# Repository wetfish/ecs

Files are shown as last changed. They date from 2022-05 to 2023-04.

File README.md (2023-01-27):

# ecs
Environmental control systems

---

# sensorlogger.py
Used for logging temperature data to a raspberry pi's SD card. Requires DS18B20, DHT11, or DHT22 sensor.
### Super basic instructions

- Write raspberry pi OS to an SD card
- Run `sudo apt update`
- Then `sudo apt install python3-pip`
- Then `pip3 install -r requirements.txt`
- Then `python3 simplelogger.py 26 dht11`

#### Installation and usage
Requires python 3

Requires 1-wire interface to be enabled in raspi-config for ds18b20 sensor https://www.raspberrypi-spy.co.uk/2018/02/enable-1-wire-interface-raspberry-pi/

To install dependencies:

`pip install -r requirements.txt`
  
Usage:

`python3 sensorlogger.py [GPIO pin #] [Sensor type] {-f output filename}`

GPIO pin # and sensor type required. When -f is used, an output filename can be specified for the log file, defaults to [sensorname].log when -f is not used

GPIO pin # is the BCM pin #, not the board pin # https://raspberrypi.stackexchange.com/questions/12966/what-is-the-difference-between-board-and-bcm-for-gpio-pin-numbering

Sensor type is all lower case. dht11, dht22, or ds18b20

## quickcsvplotter.py
Plots the data collected by sensorlogger.py

Usage:

`python3 quickcsvplotter.py [csv filename 1] [csv filename 2] ... [csv filename n]`

Providing filenames in command line is optional. If no filenames are specified, all csvs in current directory will be plotted.

---

# sensorlogger.ino
Used to log data from a variety of sensors to an SD card, using a  NodeMCU ESP8266 devkit. Other devices can be used, but some cannot fit the full program onto the flash memory. Also prints data to serial (115200 BAUD) , so can be monitored while running as well. A continuously flashing LED indicates an error with either the SD card or one of the sensors.

### Supported sensors:
- DS18B20
- BME280
- Phototransistor (like PT334-6C)
- INA219
- Anemometer

### Log file:
The first line acts as column headers for the rest of the file. Each of the following lines consist of comma separated values for each of the measurements being taken. Each line is a seperate set of measurements.

### Error blink code:
- 2x blink: SD initialization error
- ~10x blink: SD init ok, but SD write error

## Flashing the NodeMCU ESP8266
To add support for NodeMCU board to Arduino IDE:

1. Go to File -> Preferences -> "Additional Boards Manager URLs:", and paste https://arduino.esp8266.com/stable/package_esp8266com_index.json into the box. Click OK.
2. Now click Tools -> Board: -> "Boards Manager...". In the seach bar, type "esp8266". Click on the esp8266 package, then click "Install".
3. Restart Arduino IDE. Click Tools -> Board: -> ESP8266 Boards -> NodeMCU 1.0 (ESP-12E Module)

To install required libraries:

- Click Tools -> Manage Libraries..., then enter [library name] into search bar. Click "Install". If you are asked if you also want to install missing dependencies, click "Install All".

Do the above step for the following libraries:
 - Dallas Temperature
 - Adafruit BME280 Library
 - Adafruit ADS1X15
 - Adafruit INA219

 Now you should be able to open the sensorlogger.ino sketch in the Arduino IDE and upload it to the NodeMCU ESP board.

 ## sensorlogger.ino parameters
 Near the top of sensorlogger.ino, there is a list of parameters than can be changed according to your own hardware setup.

 **LOG_FILENAME** -> This is a string indicating the name of the log file. It must fit the 8.3 short format, so it can have a maximum of 8 characters, a period, and then 3 more characters. Each time the program is restarted, a new file is created, so if your LOG_FILENAME = "log.txt", log.txt will be created on the SD card. On subsequent runs, an underscore and a numeral will be appended to the filename.

 **POLL_INTERVAL** -> This is how long to wait between sensor readings, in milliseconds. 

 **NO_SD** -> This is a boolean that allows the program to run without an SD card connected. Set to "true" to run program without SD card, "false" if you want to write data to SD.

 **SENSORS** -> This is an array that represents which sensors to take readings from. Each element is a struct of {(enum)[sensor type], (uint8_t)[pin number or hardware address]}. Valid sensor types are: ds18b20, voltmeter, bme280, ads1115, ads1115anemometer, and ina219. For the INA219, the second field will need to contain the hardware address. If you have not altered the INA219 module at all, the address is 0x40. For the BME280, the second field is irrelevant and any int works. For the devices connected through the ADS1115, the second field is the pin on that board.

 **DS18B20ADDRESSES** -> This is an array of the addresses of DS18B20 sensors being used and a corresponding label for each one. The addresses are device-specific, so will need to found by running ds18b20AddressFinder.ino with each of your sensors. The label will appear at the column header in the log file so we know which temperature readings come from which sensors.

**CS_PIN** -> This is the chip select (CS) pin for the SPI interface af the SD card. 

**LED_PIN** -> This is the pin for the indicator LED. By default it is one of the built-in LEDs on the NodeMCU, but can be an external one if desired.

# ds18b20AddressFinder.ino
Use this to find addresses of all DS18B20 sensors being used. Make sure to mark each sensor as well so they don't get mixed up. It only requires the DallasTemperature library, which should have already been installed.

## ds18b20AddressFinder.ino parameters

**ONEWIRE_PIN** -> This is the pin that the data wire of the DS18B20 is connected to.

## Getting your device addresses
1. Connect first sensor to NodeMCU with ds18b20AddressFinder.ino.
2. Connect NodeMCU to computer with Arduino IDE (or other serial monitor).
3. Open serial monitor and make sure it's at 115200 BAUD.
4. Every 5 seconds, the sensor's address will be printed. Copy that to sensorlogger.ino or just record it for later.
5. Repeat for each DS18B20 you intend to use. Remember to indicate somehow which sensor corresponds to which address.

---

# sensorserial.ino and get_data_from_mcu.py
Used to send data from a variety of sensors to a PC via USB, using a  NodeMCU ESP8266 devkit. A continuously flashing LED indicates an error with either the SD card or one of the sensors. This program is very similar to sensorlogger.ino, but it sends data to a PC running a python script rather than log to SD, and the python script controls the timiing of the sensor polls.

## Setting up NodeMCU ESP8266
Follow the same steps as for sensorlogger.ino. Then plug the NodeMCU via USB into a computer that will run the python script.

## get_data_from_mcu.py
To be run from terminal on a PC, Raspberry Pi, etc:

`python3 get_data_from_mcu.py [poll_interval]`

[poll_interval] is the time in seconds between sensor polls, and is an optional argument. Default poll interval is 3 seconds.

Whenever restarting script, NodeMCU should be restarted as well.

# GoPro as webcam setup
https://github.com/jschmid1/gopro_as_webcam_on_linux

- Install gopro_as_webcam_on_linux:

	`sudo su -c "bash <(wget -qO- https://cutt.ly/PjNkrzq)" root`

- Install dependencies:

	`sudo apt install ffmpeg v4l2loopback-dkms curl vlc`

- Plug gopro into computer via USB (can be without battery and sd card) and in new terminal:

	`sudo gopro webcam -n -a`

	This starts gopro in webcam mode using auto settings (-a), and no input from user (-n).

- Check for the device id with:

	`ls -l dev/video*`

	This is my result:

	>crw-rw----+ 1 root video 81, 0 Jan  9  2022 /dev/video0
	>
	>crw-rw----+ 1 root video 81, 1 Jan  9  2022 /dev/video1
	>
	>crw-rw----+ 1 root video 81, 2 Jan 25 14:40 /dev/video42

	/dev/video0 and 1 both referred to the laptop's webcam, so /dev/video42 is the gopro.

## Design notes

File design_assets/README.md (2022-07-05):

shelter assembly

## 3D Printed Parts
All 3D printed parts should be printed in PETG or other plastic that can withstand some heating.

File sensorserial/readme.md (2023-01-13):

## Sensorserial for NodeMCU dev board (ESP8266) and a computer running python scripts

If using Arduino IDE to program microcontroller, rename src/main.cpp to sensorserial.ino

Connect microcontroller that is running sensorserial program to a computer via USB. On the computer, run get_data_from_mcu.py to generate a log file from the microcontroller's sensor readings.

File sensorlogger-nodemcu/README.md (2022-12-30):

## Sensorlogger for NodeMCU dev board (ESP8266)

If using Arduino IDE to program microcontroller, rename src/main.cpp to sensorlogger.ino

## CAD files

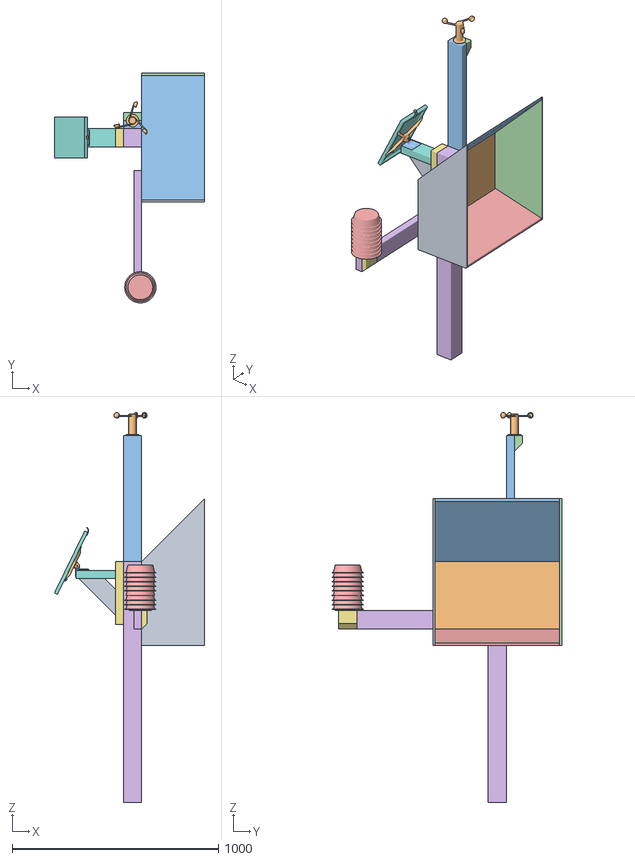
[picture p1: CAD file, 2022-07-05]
design_assets/mount_and_shelter_design v6.obj
727.6 x 1114.1 x 1890.0
left panel
back panel
top panel
right_panel
bottom panel
2x4-vert
2x4-horiz
2x4-brace

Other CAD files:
design_assets/Enclosure drain v15.f3d
design_assets/INA219_mount v14.f3d
design_assets/LM2596_mount_double v5.f3d
design_assets/MCU_PCB_mount v14.f3d
design_assets/ads1115_mount v10.f3d
design_assets/battery shim v4.f3d
design_assets/battery_clip v1.f3d
design_assets/cable gland inserts v3.f3d
design_assets/header_bus_mount v4.f3d
design_assets/mount_and_shelter_design v5.f3z
design_assets/panel_mount v25.f3d
design_assets/stevenson_spacer_2nd_bottom v2.f3d
design_assets/stevenson_spacer_and_template v20.f3d
design_assets/stevenson_spacer_bottom v5.f3d
design_assets/stevenson_spacer_top v2.f3d
design_assets/wanderer_mount v2.f3d

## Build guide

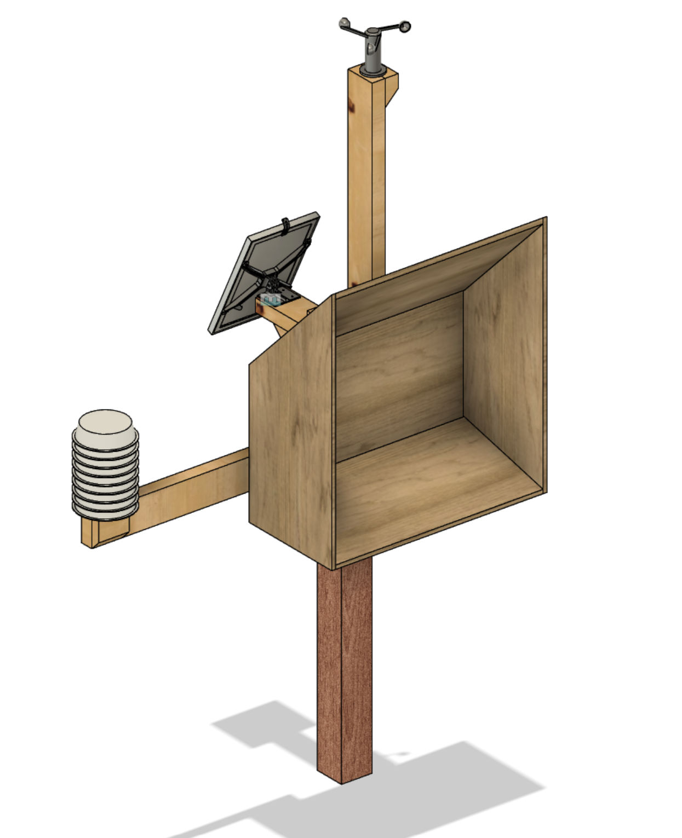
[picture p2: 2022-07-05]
design_assets/shelter assembly.png

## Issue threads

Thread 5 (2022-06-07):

Add phototransistor-specific reading to sensorlogger.ino

quinnc0, 2022-06-07:
The program currently sees this sensor as just a voltmeter, but the raw voltage reading isn't very intuitive. A threshold voltage to determine whether there is or isn't light might be more useful. Some outdoors testing may be required to determine what readings occur under what lighting conditions.

Closed 2022-06-23.

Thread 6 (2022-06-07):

Test anemometer to determine characteristics of output signal

quinnc0, 2022-06-07:
The anemometer's signal is expected to be under 2V. If this is true, the ADS gain might be able to be set for higher precision. Also, it may be useful to test that the voltage to windspeed mapping in sensorlogger.ino is correct, though I'm not sure of a good way to calibrate that.

quinnc0, 2022-09-19:
The current voltage to windspeed mapping definitely seems off. It seems to report windspeeds much lower than expected, but I don't know by how much. Current mapping is based on the data from[ adafruit's product page](https://www.adafruit.com/product/1733). It should be confirmed that this mapping is implemented correctly, and if so, devise a way to calibrate the sensor better.

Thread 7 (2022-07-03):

NodeMCU usually fails to boot with SD card inserted.

quinnc0, 2022-07-03:
This is a very intermittent problem so it has been hard to diagnose the cause of it. When an SD card is inserted into the SD card reader, the NodeMCU can fail to boot. As a workaround, a 3s delay was added to the beginning of the sensorlogger.ino program to allow the SD card to be inserted just after boot. This workaround doesn't always work either, but it's more consistent.

quinnc0, 2022-09-22:
SD card was replaced on 9/18. So far it has booted fine with the new SD card, but due to the intermittent nature of the problem, it's probably too early to determine if  the issue is truly fixed.

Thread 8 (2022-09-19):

BME sensor failure

quinnc0, 2022-09-19:
The BME sensor failed sometime within 2 months after installation. This may be due to moisture, as the wind was a lot stronger than I anticipated. If so, this could be a simple fix of either shielding the sensor better from rain, or simply swapping a waterproof ds18b20 into the BME's position.

quinnc0, 2023-01-25:
Cause of sensor failure still undetermined, but BME was replaced and better shielded from rain and debris. So far so good.

Closed 2023-01-25.

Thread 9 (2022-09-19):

Sensor failure causes microcontroller reboot

quinnc0, 2022-09-19:
Program should be rewritten to allow sensor failure without rebooting microcontroller. This should be how it works with some of the sensors already, but at least the BME280 will not allow the program to run when missing. The BME280 uses I2C communication, so possibly the other I2C devices will fail in a similar manner (INA219 & ADS1115).

It would be much better to just gather garbage data on failed sensors because at least we'd still get the data from the working sensors.

quinnc0, 2022-09-22:
All I2C sensors will return NAN when they had failed or were not present. Previously, the program kept trying to get a reading until it no longer returned NAN. The nodeMCU times out and reboots after spending a few seconds without repeating its main loop. So it would reboot when a sensor returned NAN for a few seconds. Now the sensors will only retry a few times before accepting a NAN result.

Closed 2022-09-22.

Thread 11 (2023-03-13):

Station M1 too weak to handle Gopro webcam stream?

quinnc0, 2023-03-13:
For some reason, gopro will not stream at any other resolution than 1080, and at 30 fps. Station M1 can only process about 7 fps at that resolution it seems. This leads to clips being delayed by minutes. Also, after some time, the webcam stream buffer is filled and then I think it just starts dropping frames.

The Station M1 was tested with cheap logitech webcam that outputs 320x240 at 30 fps. There is no problem handling this stream and clips are generated in real time and at the correct speed.

Maybe there is a way to lower the gopro resolution to allow the Station M1 to keep up. Otherwise I think the only options are finding a more suitable camera or a more powerful sbc.

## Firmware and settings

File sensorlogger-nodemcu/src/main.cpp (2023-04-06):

#include <SPI.h>
#include <SD.h> // http://www.arduino.cc/en/Reference/SD

/* 
https://www.milesburton.com/Dallas_Temperature_Control_Library (for DS18B20)
https://github.com/adafruit/Adafruit_BME280_Library 
https://github.com/adafruit/Adafruit_ADS1X15 (ADC board)
https://github.com/adafruit/Adafruit_INA219 (Volt/Ammeter)
*/

#include "sensorwrap.h"
#include "ds18b20wrap.h"
#include "voltmeterwrap.h"
#include "bme280wrap.h"
#include "ads1115voltmeterwrap.h"
#include "ads1115anemometerwrap.h"
#include "ads1115phototransistorwrap.h"
#include "ina219wrap.h"

#include "oleddisplay.h"

// These are the valid sensor models than can be used.
enum SensorModels
{/*dht11, dht22,*/ ds18b20, voltmeter, bme280, ads1115, ads1115anemometer, ads1115phototransistor, ina219};
struct SensorInfo
{
	SensorModels model;
	uint8_t pin; // data pin of that sensor - for I2C devices, this usually is arbitrary
};

// Pins printed on the NodeMCU board are not the same as the esp8266 GPIO pin number, which is what we actually need to use here
namespace NodeMcuPins
{
	enum : uint8_t
	{
		D0 = 16, D1 = 5, D2 = 4, D4 = 2,
		D5 = 14, D6 = 12, D7 = 13, D8 = 15,
		RX = 3, TX = 1, SD2 = 9, SD3 = 10
	};
}
namespace Ads1115Pins
{
	enum : uint8_t
	{
		A0 = 0, A1 = 1, A2 = 2, A3 = 3
	};
}
//----------------------------------------------------------
// Change filename, polling interval, SD logging, and sensor types here
const String LOG_FILENAME = "log.txt"; // first line is column labels, so throw that away when using the file for computations
const unsigned long POLL_INTERVAL = 3000; // in milliseconds
const bool NO_SD = false; // disables sd card logging
const SensorInfo SENSORS[] = 
{// {sensor model, pin # (or I2C address for INA219)}
	{ina219, 0x40}, 
	{ina219, 0x41}, 
	//{ads1115, Ads1115Pins::A0}, 
	{bme280, 0},
	{ds18b20, NodeMcuPins::SD3},
	{ads1115phototransistor, Ads1115Pins::A0},
	{ads1115anemometer, Ads1115Pins::A1},
	//{voltmeter, A0}
};

// --- DS18B20 Addresses ---
// List sensor addresses here. Get them individually with ds18b20AddressFinder.ino or similar
// Labels should be where the sensor is located or something. Or some identifying factor.
const DS18B20Addresses DS18B20_ADDRESSES[] = {
		//{{0x28, 0x63, 0x1B, 0x49, 0xF6, 0xAE, 0x3C, 0x88}, "MAIN"}, // measuring electronics enclosure temp,has white heatshrink
		{{0x28, 0xDC, 0xA0, 0x49, 0xF6, 0xEB, 0x3C, 0xF0}, "Batt"}, // measuring battery enclosure temp, has white heatshrink
		{{0x28, 0x6A, 0x64, 0x49, 0xF6, 0xBE, 0x3C, 0xF0}, "MCU"} // has red heatshrink
		};

uint8_t NUM_SENSORS = sizeof(SENSORS) / sizeof(SENSORS[0]);
uint8_t NUM_DS18B20S = sizeof(DS18B20_ADDRESSES) / sizeof(DS18B20_ADDRESSES[0]);

//----------------------------------------------------------
// Other Pin selection
// Pins D5 (SCK), D6(MISO), D7(MOSI), and D8(CS) on NodeMCU are required for the SPI for the SD card reader, so don't use them.
// On NodeMCU, pin D1(SCL) and D2(SDA) for I2C communication
const uint8_t CS_PIN = NodeMcuPins::D8;// cs pin for sd card
const uint8_t LED_PIN = LED_BUILTIN_AUX; // led pin for indicator. not required.

/*
// DHT sensors
class DhtWrap : public SensorWrap
{
	private:
	DHT dht;

	public:
	DhtWrap(uint8_t pin_num, uint8_t dht_type): dht(pin_num, dht_type)
	{
		num_readings = 2; // 1 temp and 1 humidity
		labels = "DHT-Temp(F), DHT-RH(%)";
	}

	void init()
	{
		Serial.println("DHT init");
		dht.begin();
	}

	float takeReading(uint8_t reading_num)
	{
		switch (reading_num)
		{
			case 0:
				return dht.readTemperature(true); // true for F, false for C
			case 1:
				return dht.readHumidity();
			default:
				return NAN;
		}
	}
};
*/

/* --------------
 * Linked list for storing list of sensors.
 * TODO: maybe get rid of list_size. Doesn't look like it's being used. or maybe just use it.
 */
template <typename T>
class LinkedList
{
	
	public:

	struct Node
	{
		T sensor;
		Node* next;
	};

	Node* head;
	uint8_t list_size;

	LinkedList<T>()
	{
		head = nullptr;
		list_size = 0;
	}

	
	Node* get_next_node(Node* curr_node)
	{
		return curr_node->next;
	}

	// add node to end of list and return pointer to that node, in case it's needed
	Node* push_back(T newData)
	{
		Node* new_node = get_new_node(newData);
		if (head == nullptr) // if this ia the start of the list
		{
			head = new_node;
		}
		else                // if this is adding to an existing list
		{
			Node* curr_node = head;
			while (curr_node->next)
			{
				curr_node = curr_node->next;
			}
			curr_node->next = new_node;
			list_size++;
		}
		return new_node;
	}

	private:
	// creates new node
	Node* get_new_node(T newSensor)
	{
		Node* newNode = new Node;
		newNode->sensor = newSensor;
		newNode->next = nullptr;
		return newNode;
	}
};

/* =================================
 * DataLogger
 * Makes list of sensors, writes data from each of them to a new file based on the given filename base.
 * Uses LinkedList class and all of the SensorWrap children.
 * //TODO: possibly restructure this so it's easier to actually access and do stuff with any 
 *  of the sensor values.
 */
class DataLogger
{
	String log_fn;
	String column_labels;
	uint8_t cs_pin;
	uint8_t led_pin;
	unsigned long poll_interval;
	unsigned long last_poll;
	LinkedList<SensorWrap*>* sensor_list = new LinkedList<SensorWrap*>();
	bool did_err_msg = false;

	uint8_t total_num_readings; // total number of readings per update
	float last_sensor_readings[25]; // this should be large enough for all of our readings.

	OledDisplay display;
	
	public:
	/* 
	 * logFn- filename should be short so as to conform to 8.3 short format (8 characters + '.' + 3 characters)
	 * pollInterval- time between sensor polls in milliseconds	 *
	 */
	DataLogger(String logFn, uint8_t CSpinNo, uint8_t LEDpinNo, unsigned long pollInterval) : 
	log_fn(logFn) 
	{
		cs_pin = CSpinNo;
		led_pin = LEDpinNo;
		poll_interval = pollInterval;
		last_poll = 0;
		column_labels = "Time(s)";
		total_num_readings = 1; // we will always at least be recording time
	}
	
	// initializers. these are run in setup()
	void init_sd()
	{
		if(NO_SD)
		{
			Serial.println("Not logging to SD.");
			return;
		}
		Serial.println("CS_pin: " + String(cs_pin));
		Serial.println("led_pin: " + String(led_pin));
		Serial.println("Poll Intvl: " + String(poll_interval));

		// set up led
		pinMode(led_pin, OUTPUT);
		Led(true);

		// check if sd card is not set up
		while (!SD.begin(cs_pin))
		{
			// error
			Serial.println("SD err " + String(cs_pin));
			//error_blink();
			// blink 2x quick, then try again
			Led(true);
			delay(100);
			Led(false);
			delay(100);
			Led(true);
			delay(100);
			Led(false);
			delay(700);

		}
		Led(true);
		// get the right filename
		log_fn = set_next_filename();
	}

	void init_sensors(const SensorInfo sensors[], uint8_t& num_sensors)
	{
		display.init();
		list_sensors(sensors, num_sensors);
		// iterate through list of sensors to get the column labels from all of them
		LinkedList<SensorWrap*>::Node* current_sensor = sensor_list->head;
		while(current_sensor)
		{
			current_sensor->sensor->init();
			column_labels += ", " + current_sensor->sensor->labels;
			total_num_readings += current_sensor->sensor->num_readings;
			current_sensor = sensor_list->get_next_node(current_sensor);
		}
		// show what each column means
		Serial.println("\n" + column_labels);
		if(!NO_SD)
		{	// when parsing the CSV, either throw away all lines starting with #, or just the first line
			write_file("# " + column_labels);
		}
		//Serial.println("-------------------------------");
	}

	// takes readings and writes to file
	void update()
	{
		if(timekeeper())
		{
			String sensor_data = read_from_sensors();
			Serial.println(sensor_data);
			oled_display();
			// if not using sd stop here
			if(NO_SD)
			{
				return;
			}
			write_file(sensor_data);
		}
	}

	private:
	
	// populate list
	// add another case for each new sensor class added 
	void list_sensors(const SensorInfo sensors[], uint8_t& num_sensors)
	{
		for (int i = 0; i < num_sensors; i++)
		{
			switch (sensors[i].model)
			{
			//case dht11:
			//	sensor_list->push_back(new DhtWrap(sensors[i].pin, DHT11));
			//	break;
			//case dht22:
			//	sensor_list->push_back(new DhtWrap(sensors[i].pin, DHT22));
			//	break;
			case ds18b20:
			{
				LinkedList<SensorWrap*>::Node* this_node;
				this_node = sensor_list->push_back(new DS18B20Wrap(sensors[i].pin));
				LinkedList<DS18B20Wrap*>::Node* ds_node = (LinkedList<DS18B20Wrap*>::Node*)this_node;
				ds_node->sensor->set_addresses(DS18B20_ADDRESSES, NUM_DS18B20S);
			}
				break;
			case voltmeter:
				sensor_list->push_back(new VoltmeterWrap(sensors[i].pin));
				break;
			case bme280:
				sensor_list->push_back(new BME280Wrap());
				break;
			case ads1115:
				sensor_list->push_back(new ADS1115VoltmeterWrap(sensors[i].pin));
				break;
			case ads1115anemometer:
				sensor_list->push_back(new ADS1115AnemometerWrap(sensors[i].pin));
				break;
			case ads1115phototransistor:
				sensor_list->push_back(new ADS1115PhototransistorWrap(sensors[i].pin));
				break;
			case ina219:
				sensor_list->push_back(new INA219Wrap(sensors[i].pin));
				break;
			default:
				break;
			}
		}
	}

	// increments filename if one already exists with given name.
	String set_next_filename()
	{
		String temp_fn = log_fn;
		String base_fn;
		String extension;
		unsigned long i = 1;
		if (SD.exists(temp_fn))
		{
			size_t dot_loc= temp_fn.lastIndexOf(".");
			base_fn = temp_fn.substring(0, dot_loc);
			extension = temp_fn.substring(dot_loc);

			while (SD.exists(temp_fn))
			{
				String i_string = "_" + String(i);
				if (base_fn.length() + i_string.length() > 8)
				{
					base_fn = base_fn.substring(0, 8 - i_string.length());
				}
				temp_fn = base_fn + i_string + extension;
				i++;
			}
		}
		Serial.println("Filename=\"" + temp_fn + "\"");
		return temp_fn;
	}

	// returns true when it's time for another reading
	bool timekeeper()
	{
		yield(); //TODO figure out when to actually use this yield thing
		unsigned long now_ms = millis();
		if (now_ms - last_poll > poll_interval)
		{
			last_poll = now_ms;
			return true;
		}
		else
		{
			return false;
		}
	}

	// reads data from sensors and stores as a csv string
	// uses last_poll as time value
	String read_from_sensors()
	{
		// record time
		String datum = String(last_poll/1000);
		last_sensor_readings[0] = last_poll/1000;
		// get data from sensors
		LinkedList<SensorWrap*>::Node* current_sensor = sensor_list->head;
		// keep track of readings
		uint8_t reading_index = 1;
		while(current_sensor)
		{
			// record reading into string
			for (int i = 0; i < current_sensor->sensor->num_readings; i++)
			{
				// make sure a valid reading is taken
				float temp_f; // = current_sensor->sensor->getReading(i);
				uint8_t num_tries = 0; // count how many tries to read, so can timeout
				do
				{
					temp_f = current_sensor->sensor->getReading(i);
					if (num_tries > 10) // 10 tries before timeout sounds good?
					{
						break;
					}
					num_tries++;
				} while (isnan(temp_f));
				datum += "," + String(temp_f);
				last_sensor_readings[reading_index] = temp_f;
				reading_index++;
			}

			// go to next sensor
			current_sensor = sensor_list->get_next_node(current_sensor);
		}

		return datum;
	}

	// writes string to file. Opens file, writes, closes file.
	void write_file(String to_write)
	{
		File log_file = SD.open(log_fn, FILE_WRITE);
		uint8_t retry_num = 0;
		while(!log_file) // if file can't be opened, show error
		{
			Serial.println("Error opening file \"" + log_fn + "\"");
			Serial.println("Fname must be in 8.3 format."); // 8 characters + . + 3 characters
			retry_num++;
			delay(100);
			if (retry_num > 30) // resets device after a while
			{
				error_blink();
			}
		}

		// otherwise, everything is fine
		log_file.println(to_write);
		log_file.close();
	}

	// formats data for oled display
	void oled_display()
	{
		// which sensors do we want to display on the oled (10 max i think  for the 128x32)
		static const String ID_LABELS[] = // These must == exact string label in the corresponding sensor's class
		{
			"BME280 Temp(F)", "BME280 Humidity(%)", "DS18 Temp(F)[Batt]", "Voltage[0x40]", "Power(mW)[0x40]", "Wind Speed"
		};
		static const String DISPLAY_LABELS[] = // This will be displayed on the oled before the measurement. match these to ID_LABELS.
		{
			"Air:", "Air:", "Batt:", "Batt:", "Batt:", "Wnd:"
		};
		static const String DISPLAY_UNITS[] = // This will be displayed on the oled after the measurement. match these to ID_LABELS
		{
			"F", "%", "F", "V", "mW", "mph"
		};
		uint8_t NUM_DISPLAYED_VALUES = sizeof(ID_LABELS) / sizeof(ID_LABELS[0]);
		float display_values[7]; // 4 lines on the display, 2 values can fit per line, but time will take one slot
			
		// keep track of readings
		for(uint8_t label_index = 0; label_index < NUM_DISPLAYED_VALUES; label_index++)
		{
			// iterate through sensor list and get last readings
			LinkedList<SensorWrap*>::Node* current_sensor = sensor_list->head;
			
			// flag to determine if we found the sensor we want
			bool found_sensor = false;
			while(current_sensor)
			{
				// record reading into string
				String current_full_label = current_sensor->sensor->labels;
				
				for (uint8_t i = 0; i < current_sensor->sensor->num_readings; i++)
				{	
					//print the labels for this sensor and the label we are looking for
					//Serial.println("current_full_label: " + current_full_label + ".\nlooking for:        " + ID_LABELS[label_index]+".");
					// if the current reading is the one we want
					if(current_full_label == ID_LABELS[label_index] || current_full_label.startsWith(ID_LABELS[label_index]))
					{
						display_values[label_index] = current_sensor->sensor->last_reading[i];
						found_sensor = true;
						break;
					}
					// if there are more sensor readings left on this sensor, cut the beginning off the label
					if(i+1 < current_sensor->sensor->num_readings) 
					{
						// snip the first label off the string, along with the comma and space
						current_full_label = current_full_label.substring(current_full_label.indexOf(',') + 2);
					}
				}
				// if we haven't found the sensor yet
				if(!found_sensor)
				{
					display_values[label_index] = -196.6; // error code
				}

				// go to next sensor
				current_sensor = sensor_list->get_next_node(current_sensor);
			}
		}

		// make strings for display - the array size should = display_values[] + 1
		String display_value_strings[8];
		// make sure each value is less than 4 characters long. if not, round it
		for(uint8_t i = 0; i < NUM_DISPLAYED_VALUES; i++)
		{		
			// if our sensor is errored, display dashes
			if(abs(display_values[i] + 196.6) < 0.01)
			{
				display_value_strings[i] = "--";
				continue;
			}

			else if (display_values[i] < 10)
			{
				display_values[i] = round(display_values[i] * 100) / 100;
			}
			else if (display_values[i] < 100)
			{
				display_values[i] = round(display_values[i] * 10) / 10;
			}
			else
			{
				display_values[i] = round(display_values[i]);
			}
			// convert to string and remove trailing zeros
			display_value_strings[i] = removeTrailingZeros(String(display_values[i]));
			// check if display will be greater than 10 char
			if((display_value_strings[i] + DISPLAY_UNITS[i] + DISPLAY_LABELS[i]).length() > 10)
			{
				// if so, round it some more
				// if we need one less character:
				if ((display_value_strings[i] + DISPLAY_UNITS[i] + DISPLAY_LABELS[i]).length() - 10 == 1)
				{
					if (display_values[i] < 10)
					{
						display_values[i] = round(display_values[i] * 10) / 10;
					}
					else
					{
						display_values[i] = round(display_values[i]);
					}
				}
				// if we need two less characters:
				else
				{
					display_values[i] = round(display_values[i]);
				}
				// convert to string and remove trailing zeros
				display_value_strings[i] = removeTrailingZeros(String(display_values[i]));
			}
		}

		String display_string[4];
		// 4 lines of display
		for (uint8_t i = 0; i < 4; i++)
		{
			if(i < NUM_DISPLAYED_VALUES)
			{
				display_string[i] = DISPLAY_LABELS[i] + display_value_strings[i] + DISPLAY_UNITS[i];
				// add spaces to make sure the second column is aligned (column 1 is 10 chars long)
				while(display_string[i].length() < 10)
				{
					display_string[i] += " ";
				}
				if(i + 4 < NUM_DISPLAYED_VALUES)
				{	// second column stuff, if it exists
					display_string[i] += " " + DISPLAY_LABELS[i+4] + display_value_strings[i+4] + DISPLAY_UNITS[i+4];
				}
			}
		}
		if (NUM_DISPLAYED_VALUES < 4)
		{
			display_string[3] = "          ";
		}		
		display_string[3] += " t:" + String(float(last_poll) / 3600000) + "hrs";
		display.display(display_string);
	}

	// converts float to string and removes trailing zeros
	String floatToString(float value) {
	char result[12]; // increase size if needed
		dtostrf(value, 0, 2, result);  // convert float to char array with 2 decimal places (change this value as needed)
		String stringResult = String(result);

		// Removes any trailing zeros from decimal point
		int lastIndex = stringResult.length() - 1;
		while (stringResult.charAt(lastIndex) == '0') {
			lastIndex--;
		}
		if (stringResult.charAt(lastIndex) == '.') {
			lastIndex--;
		}
		stringResult.remove(lastIndex + 1, stringResult.length());

		return stringResult;
	}

	// remove trailing zeros from a string
	String removeTrailingZeros(String str)
	{
		// make sure there is a decimal point
		if (str.indexOf('.') == -1)
		{
			return str;
		}
		// remove trailing zeros
		int lastIndex = str.length() - 1; // index of last char
		while (str.charAt(lastIndex) == '0') // if there is a zero, mark it for removal
		{
			lastIndex--;
		}
		if (str.charAt(lastIndex) == '.') // if there is a decimal point, mark it for removal
		{
			lastIndex--;
		}
		str.remove(lastIndex + 1, str.length()); // remove all chars after the last non-zero char
		return str;
	}
	
	// operates led
	void Led(bool isOn)
	{
		digitalWrite(led_pin, !isOn);
	}
	// just blinks led forever. stops execution of any other code, then resets
	void error_blink()
	{
		//Serial.println("error");
		bool is_on = false;
		uint8_t blink_times = 0;
		while (true)
		{
			is_on ^= true; // toggle led state
			Led(is_on);
			delay(100);
			blink_times++;
			while (blink_times > 30){} // after few sec, get stuck - then reset through wdt
		}
	}
};

DataLogger data_logger(LOG_FILENAME, CS_PIN, LED_PIN, POLL_INTERVAL);

void setup()
{
	Serial.begin(115200);
	delay(3000);
	data_logger.init_sd();
	data_logger.init_sensors(SENSORS, NUM_SENSORS);
}

void loop()
{
	data_logger.update();
}

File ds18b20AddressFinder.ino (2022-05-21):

/*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
 * To use, hook up one DS18B20 sensor at a time. Run program and use serial monitor to note 
 * address of each sensor tested. This will be needed when wiring multiple DS18B20 sensors
 * in parallel so we know which one is which.
 * 
 * DeviceAddress is an 8 element array of uint8_t, so address can be stored like so:
 * DeviceAddress sample_addr = {0x28, 0x63, 0x1B, 0x49, 0xF6, 0xAE, 0x3C, 0x88};
 */

#include <Arduino.h>
#include <DallasTemperature.h> // https://www.milesburton.com/Dallas_Temperature_Control_Library (for DS18B20)

// Pins printed on the NodeMCU board are not the same as the esp8266 GPIO pin number, which is what we actually need to use here
namespace NodeMcuPins
{
	enum : uint8_t
	{
		D0 = 16, D1 = 5, D2 = 4, D4 = 2,
		D5 = 14, D6 = 12, D7 = 13, D8 = 15,
		RX = 3, TX = 1, SD2 = 9, SD3 = 10
	};
}
// pick a pin for the data:
#define ONEWIRE_PIN NodeMcuPins::SD3

OneWire onewire(ONEWIRE_PIN);
DallasTemperature ds18b20(&onewire);
DeviceAddress sensor_address;
// function to print a device address
void printAddress(DeviceAddress deviceAddress);

void setup() 
{
  Serial.begin(115200);

  ds18b20.begin();
  Serial.println("number of devices: ");
  Serial.println(ds18b20.getDeviceCount(), DEC);

  if (!ds18b20.getAddress(sensor_address, 0)) 
  {
    while(1)
    {
      Serial.println("Unable to find address for Device 0");
      delay(5000);
    }
  }
}

void loop() 
{
  // show the address we found on the bus
  Serial.print("Device Address: ");
  printAddress(sensor_address);
  Serial.println();

  delay(5000);
}

// function to print a device address
void printAddress(DeviceAddress deviceAddress)
{
  Serial.print("{");
  for (uint8_t i = 0; i < 8; i++)
  {
    Serial.print("0x");
    // zero pad the address if necessary
    if (deviceAddress[i] < 16) Serial.print("0");
    Serial.print(deviceAddress[i], HEX);
    // add comma if it's not the last byte
    if (i < 7)
    {
      Serial.print(", ");
    }
  }
  Serial.print("}");
}

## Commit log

2019-06-07 Complete basic sensor logging script for DHT11
2019-06-11 Add proper CLI and framework for other sensors
2019-06-13 Update README for sensorlogger.py usage and installation
2022-03-11 Added quickcsvplotter.py
    To quickly visualize data collected by sensorlogger.py
2022-03-27 Added sensorlogger.ino
2022-03-27 Update readme with sensorlogger.ino instructions
2022-03-31 Rename sensorlogger.ino to simplelogger.ino
    This file more closely mirrors the function of simplelogger.py, so renamed to reflect that.
2022-04-02 Add sensorlogger.ino
    Sensorlogger.ino adds support for ds18b20 sensor
2022-04-02 Update readme for sensorlogger.ino
2022-04-04 Add support for voltmeter
2022-04-09 Add adafruit anemometer support
    Through ADS1015 ADC
2022-04-30 Add support for multiple ds18b20s
    Multiple DS18B20s can now be used on the same pin. NodeMCU printed pin numbers are now converted to esp8266 GPIO pin numbers in an enum.
2022-05-21 log column labels, i2c address choice added
    Log file's first line is now column labels. Throw this line out when plotting data.
    INA219 I2C address option added to allow multiple INA219 instances/devices.
2022-05-22 Add DS18B20 addressing options
    Can now specify which DS18B20 sensor is which, provided you know its address.
2022-06-06 add detailed instructions for sensorlogger.ino
    How to flash NodeMCU with Arduino IDE, library installation, parameter description, DS18B20 address finding
2022-06-07 Add error msg, change INA reading
    Added error message for missing/invalid INA219 to aid troubleshooting. Removed current reading and added power reading, since current reading isn't that useful unless as a means to get power. The INA219 can do that computation for us so we'll take it.
2022-06-27 Update DS18B labels, activate all sensors
    Update DS18B20 labels to describe what they are measuring. Activate polling of all sensors.
2022-07-03 added 3 second delay at start of program
    When booting the device with SD card inserted, it often fails boot. The delay allows insert SD card after boot.
2022-07-05 Added fusion 360 source files
    Added .f3d source files for all printed parts
    [ads1115_mount v10.f3d, battery shim v4.f3d, battery_clip v1.f3d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]
2022-07-05 added shelter mock up design
    added shelter design source file, as well as OBJ, since that can be viewed without CAD software
    [mount_and_shelter_design v5.f3z, mount_and_shelter_design v6.obj]
2022-07-05 add more 3d print source files
    [Enclosure drain v15.f3d, INA219_mount v14.f3d, LM2596_mount_double v5.f3d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]
2022-07-25 Add files via upload
    Add arduino program that sends sensor data via USB rather than store it on SD. And add python script to run on PC that communicates with the MCU and receives the sensor data.
2022-07-25 Rename sensorSerial.ino to sensorserial.ino
    changed to match convention of other files in the repo
2022-07-27 Added logging of sensor data
    Now logs to file "log.txt"
2022-09-02 add argument parser
    adds argument parser for polling interval, sensor log filename, and whether same file should be rewritten each time script is run
2022-09-22 prevents failed sensor from rebooting nodeMCU
    Allows failed sensors to send NAN as a reading instead of blocking code, which caused the nodeMCU to time out and reboot
2022-12-26 rename a sensor and activate LED
    Rename a temperature sensor to match its use and make sure main board's LED is lit when program is running successfully.
2022-12-30 create readme
    create readme and separate directory for nodemcu sensorlogger program
2022-12-31 Delete sensorlogger-nodemcu/ads1115anemometerwrap directory
    wrong location
2022-12-31 Delete sensorlogger-nodemcu/ads1115phototransistorwrap directory
    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
2022-12-31 Delete sensorlogger-nodemcu/ina219wrap directory
    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
2022-12-31 Update sensorwrap.h
    move ifndef
2022-12-31 disable sensor classes
    sensor classes in main.cpp disabled and moved to separate files
2023-01-13 switch case bug fix
    added some curly brackets
    [main.cpp]
2023-01-13 Move sensorserial to its own folder
    move sensorserial to its own folder and refactor classes into separate files. changed filename to from a .ino to main.cpp to work better with platformio.
2023-02-16 added storage for last sensor readings
2023-02-16 added storage for previous sensor readings
2023-04-06 reenable weatehr station sensors
2023-04-06 print labels of sensors during init
2023-04-06 print labels during init
